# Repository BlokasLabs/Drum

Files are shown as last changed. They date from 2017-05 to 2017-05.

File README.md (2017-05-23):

# Drum

Drum is the Blokas Edition of the [Bleep Drum](http://bleeplabs.com/store/bleep-drum-midi/). It features a built-in speaker, so the beats won't stop flowing even when there's no headphones or external speaker at hand's reach!

## Building The Source Code

The firmware has dependencies on Bounce2 and MIDI libraries. They can easily be setup from within the Arduino IDE:

1. Go to Sketch -> Include Library -> Manage Libaries...
2. Install the following libraries:
    * [Bounce2](https://github.com/thomasfredericks/Bounce2) by Thomas Ouellet Fredericks with contributions from: Eric Lowry, Jim Schimpf and Tom Harkaway.
    * [MIDI Library](https://github.com/FortySevenEffects/arduino_midi_library) by Forty Seven Effects.

After dependencies are set up, just open DRUM/DRUM.ino in [Arduino IDE](https://www.arduino.cc/en/Main/Software) and it should build successfully.

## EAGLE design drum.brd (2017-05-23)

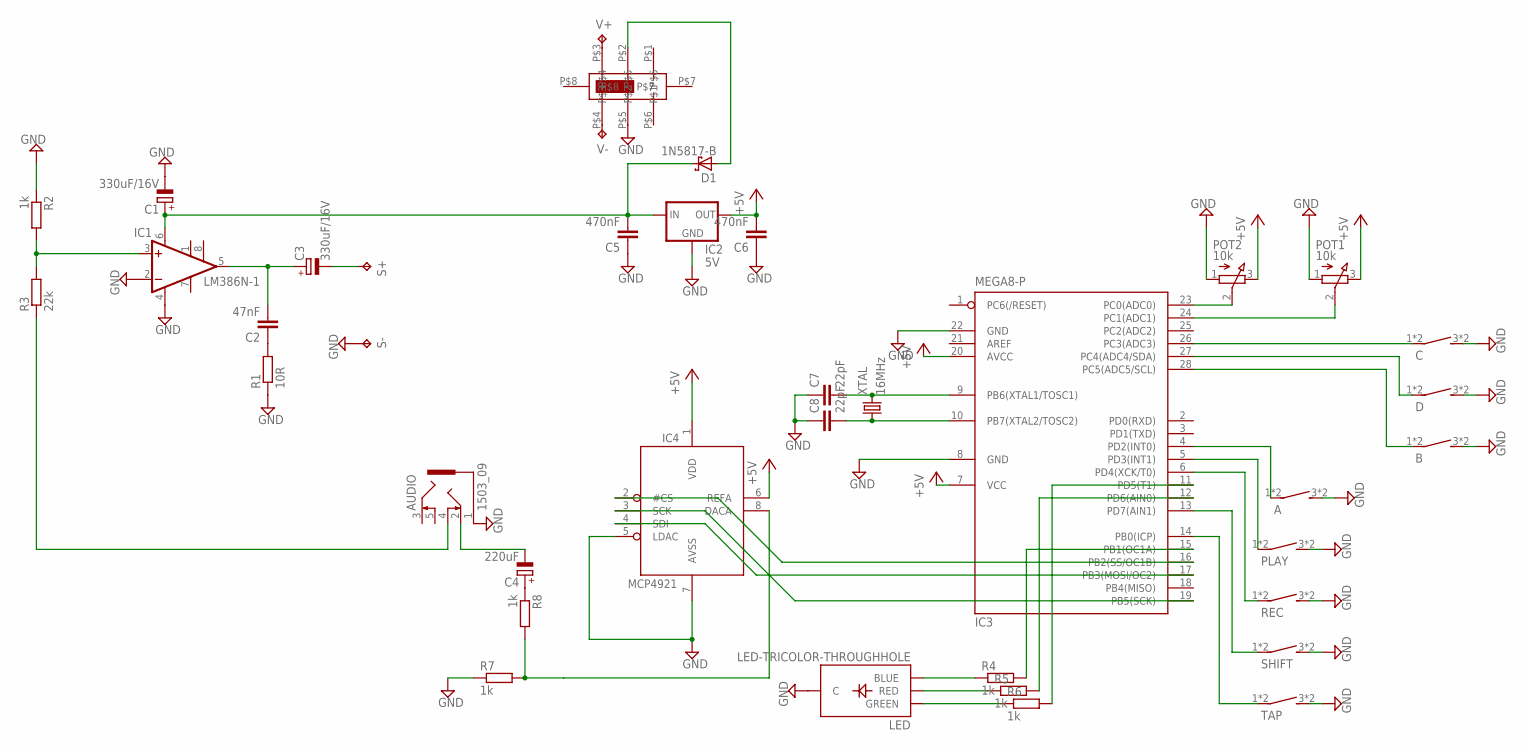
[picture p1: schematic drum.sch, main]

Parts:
A: D6R_SPSTB3F-4000; B3F-4000
AUDIO: 1503_09
B: D6R_SPSTB3F-4000; B3F-4000
C: D6R_SPSTB3F-4000; B3F-4000
C1, C3: 330uF/16V; E3,5-8
C2: 47nF; C050-024X044
C4: 220uF; E2,5-6
C5, C6: 470nF; C050-024X044
C7, C8: 22pF; C050-024X044
D: D6R_SPSTB3F-4000; B3F-4000
D1: 1N5817-B; DO41-7.6
IC1: LM386N-1; DIL08
IC2: 5V; 78LXX
IC3: MEGA8-P; DIL28-3
IC4: MCP4921; DIL08
LED: LED-TRICOLOR-THROUGHHOLE
PLAY: D6R_SPSTB3F-4000; B3F-4000
POT1, POT2: 10k; EVUFXJ
PWR: SLIDE_SW_DPDT; SS008B02P22
R1: 10R; 0207/10
R2, R4, R5, R6, R7, R8: 1k; 0207/10
R3: 22k; 0207/10
REC: D6R_SPSTB3F-4000; B3F-4000
S+: TPPAD1-17; P1-17
S-: TPPAD1-17; P1-17
SHIFT: D6R_SPSTB3F-4000; B3F-4000
TAP: D6R_SPSTB3F-4000; B3F-4000
V+: TPPAD1-17; P1-17
V-: TPPAD1-17; P1-17
XTAL: 16MHz; HC49/S

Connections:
+5V: C6.2, IC2.OUT, IC3.7 (VCC), IC3.20 (AVCC), IC4.1 (VDD), IC4.6 (REFA), POT1.3 (E), POT2.3 (E)
GND: A.3 (S), A.4 (S), AUDIO.1, B.3 (S), B.4 (S), C.3 (S), C.4 (S), C1.-, C5.1, C6.1, C7.1, C8.1, D.3 (S), D.4 (S), IC1.2 (-IN), IC1.4 (GND), IC2.GND, IC3.8 (GND), IC3.22 (GND), IC4.5 (LDAC), IC4.7 (AVSS), LED.GND (C), PLAY.3 (S), PLAY.4 (S), POT1.1 (A), POT2.1 (A), PWR.P$5, R1.1, R2.1, R7.1, REC.3 (S), REC.4 (S), S-.TP, SHIFT.3 (S), SHIFT.4 (S), TAP.3 (S), TAP.4 (S)
unnamed: C2.1, R1.2
unnamed: IC3.15 (PB1(OC1A)), R4.2
unnamed: IC3.12 (PD6(AIN0)), R5.2
unnamed: IC3.11 (PD5(T1)), R6.2
unnamed: IC3.5 (PD3(INT1)), PLAY.1, PLAY.2
unnamed: C1.+, C5.2, D1.C, IC1.6 (VS), IC2.IN
unnamed: IC3.17 (PB3(MOSI/OC2)), IC4.4 (SDI)
unnamed: A.1, A.2, IC3.4 (PD2(INT0))
unnamed: IC3.19 (PB5(SCK)), IC4.3 (SCK)
unnamed: IC3.23 (PC0(ADC0)), POT2.2 (S)
unnamed: IC3.24 (PC1(ADC1)), POT1.2 (S)
unnamed: C4.+, R8.1
unnamed: IC4.8 (DACA), R7.2, R8.2
unnamed: LED.GRN (BLUE), R4.1
unnamed: LED.BLU (RED), R5.1
unnamed: LED.RED (GREEN), R6.1
unnamed: C7.2, IC3.9 (PB6(XTAL1/TOSC1)), XTAL.2
unnamed: AUDIO.2, C4.-
unnamed: D.1, D.2, IC3.27 (PC4(ADC4/SDA))
unnamed: C8.2, IC3.10 (PB7(XTAL2/TOSC2)), XTAL.1
unnamed: C2.2, C3.+, IC1.5 (OUT)
unnamed: C3.-, S+.TP
unnamed: IC1.3 (+IN), R2.2, R3.2
unnamed: AUDIO.4, R3.1
unnamed: PWR.P$4, V-.TP
unnamed: PWR.P$3, V+.TP
unnamed: D1.A, PWR.P$2
unnamed: IC3.14 (PB0(ICP)), TAP.1, TAP.2
unnamed: IC3.6 (PD4(XCK/T0)), REC.1, REC.2
unnamed: IC3.13 (PD7(AIN1)), SHIFT.1, SHIFT.2
unnamed: C.1, C.2, IC3.26 (PC3(ADC3))
unnamed: B.1, B.2, IC3.28 (PC5(ADC5/SCL))
unnamed: IC3.16 (PB2(SS/OC1B)), IC4.2 (#CS)

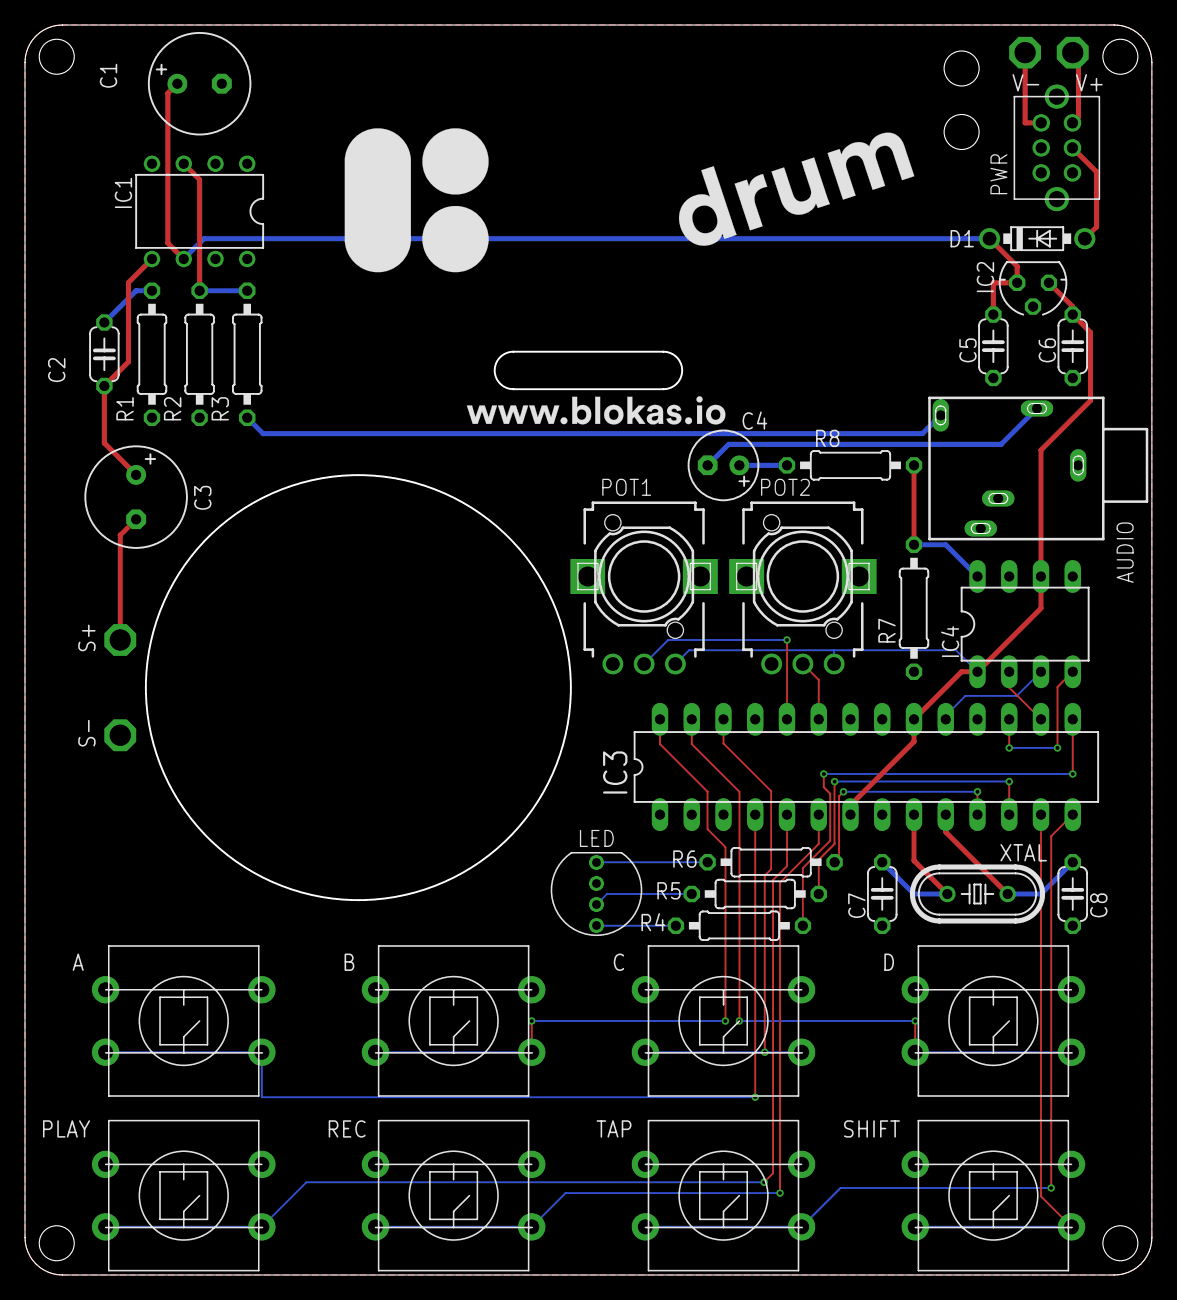
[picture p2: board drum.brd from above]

Board: 2 copper layers, 90.2 x 100.0 mm, 39 parts (0 on the bottom side), 35 nets.

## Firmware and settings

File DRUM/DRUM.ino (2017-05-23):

/*
The Bleep Drum v12
bleeplabs.com
August 2015
Dr. Bleep (John-Mike Reed) drbleep@bleeplabs.com

See http://bleeplabs.com/store/bleep-drum-midi/ for more info
All work licensed under a Creative Commons Attribution-ShareAlike 3.0

Now compatible with current versions of MIDI, bounce and pgmspace.
It is no longer necessary to edit MIDI.h

*/


#include <MIDI.h>
MIDI_CREATE_DEFAULT_INSTANCE();

#include <avr/pgmspace.h>
#include "samples.h"
#include <SPI.h>
#include <Bounce2.h>
#define BOUNCE_LOCK_OUT

Bounce debouncerRed = Bounce(); 
Bounce debouncerGreen = Bounce(); 
Bounce debouncerBlue = Bounce(); 
Bounce debouncerYellow = Bounce(); 

const char noise_table[] PROGMEM = {};

int sample_holder1, sample_holder2;
byte eee, ee, ef, eef;
byte shift, bankpg, bankpr, bout, rout, gout, prevpot2;
byte      banko = 0;
byte n1, n2;
int n3;
byte bankpb = 4;
byte beat;
int pot1 = 127;
int pot2 = 4;
long pot3, pot4;
int kick_sample, snare_sample, sample, hat_sample, noise_sample, bass_sample, B2_freq_sample, B1_freq_sample;
uint16_t increment, increment2, increment3, increment4, increment5, increment2v, increment4v;
uint32_t accumulator, accumulator2, accumulator3, accumulator4, accumulator5, accu_freq_1, accu_freq_2;
int rando;
//byte B1_sequence[16]={0,1,0,1 ,1,1,0,0 ,0,1,0,1 ,1,1,1,1};
//byte B4_sequence[16]={1,0,1,0 ,1,0,1,0 ,1,0,1,0 ,1,1,1,1};
byte B2_sequence[128] = {};
byte B3_sequence[128] = {};
byte B1_sequence[128] = {};
byte B4_sequence[128] = {
  1, 0, 0, 0 , 0, 0, 0, 0 , 1, 0, 0, 0 , 0, 0, 0, 0 , 1, 0, 0, 0 , 0, 0, 0, 0 , 1, 0, 0, 0 , 0, 0, 0, 0,
  1, 0, 0, 0 , 0, 0, 0, 0 , 1, 0, 0, 0 , 0, 0, 0, 0 , 1, 0, 0, 0 , 0, 0, 0, 0 , 1, 0, 0, 0 , 0, 0, 0, 0,
  0, 0, 0, 0 , 0, 0, 0, 0 , 0, 0, 0, 0 , 0, 0, 0, 0 , 0, 0, 0, 0 , 0, 0, 0, 0 , 0, 0, 0, 0 , 0, 0, 0, 0,
  1, 1, 1, 1 , 1, 1, 1, 1 , 1, 1, 1, 1 , 1, 1, 1, 1 , 0, 0, 0, 0 , 0, 0, 0, 0 , 0, 0, 0, 0 , 0, 0, 0, 0,
};

int B2_freq_sequence[128] = {
  0, 0, 0, 0 , 0, 0, 0, 0 , 0, 0, 0, 0 , 0, 0, 0, 0 , 0, 0, 0, 0 , 0, 0, 0, 0 , 0, 0, 0, 0 , 0, 0, 0, 0,
  0, 0, 0, 0 , 0, 0, 0, 0 , 0, 0, 0, 0 , 0, 0, 0, 0 , 0, 0, 0, 0 , 0, 0, 0, 0 , 0, 0, 0, 0 , 0, 0, 0, 0,
  0, 0, 0, 0 , 0, 0, 0, 0 , 0, 0, 0, 0 , 0, 0, 0, 0 , 0, 0, 0, 0 , 0, 0, 0, 0 , 0, 0, 0, 0 , 0, 0, 0, 0,
  0, 0, 0, 0 , 0, 0, 0, 0 , 0, 0, 0, 0 , 0, 0, 0, 0 , 0, 0, 0, 0 , 0, 0, 0, 0 , 0, 0, 0, 0 , 0, 0, 0, 0,

};
int B1_freq_sequence[128] = {};
int sample_sum;
int j, k, freq3, cc;
int kf, pf, holdkf, kfe;
int shiftcount = 0;
int t1, c1, count1, dd;
byte noise_type;
uint16_t index, index2, index3, index4, index5, index4b, index_freq_1, index_freq_2, index4bv;
uint16_t indexr, index2r, index3r, index4r, index4br, index2vr, index4vr;
int osc, oscc;
byte ledstep;
byte noise_mode = 1;
unsigned long freq, freq2;

int wavepot, lfopot, arppot;

byte loopstep = 0;
byte loopstepf = 0;

byte recordbutton, prevrecordbutton, record, looptrigger, prevloopstep, revbutton, prevrevbutton, preva, prevb;
int looprate;
//int clapbank[16]={1,0,0,0,1,0,1,0,1,1,1,1,0,0,0,0};
long prev, prev2, prev3;
byte playmode = 1;
byte play = 0;
byte playbutton, pplaybutton;
byte prevbanktrigger, banktrigger;
byte pkbutton, kbutton, B4_trigger, B4_latch, cbutton, pcbutton, B4_loop_trigger, B1_trigger, kick, B1_latch, clap, B1_loop_trigger, B4_seq_trigger, B3_seq_trigger;
byte ptbutton, tbutton, ttriger, B1_seq_trigger, B3_latch, B2_trigger, bc, B2_loop_trigger, B3_loop_trigger;
byte B2_latch, B3_trigger, B2_seq_trigger, pbutton, ppbutton;
byte kicktriggerv, B2_seq_latch, kickseqtriggerv,  B1_seq_latch, pewseqtriggerv, precordbutton;
byte measure, half;
byte recordmode = 1;
byte tap, tapbutton, ptapbutton, eigth;
long tapholder, prevtap;
unsigned long taptempo = 8000000;
unsigned long ratepot;
byte r, g, b, erase, e, preveigth;
//Bounce bouncertap = Bounce(8, 100);
byte trigger_input, trigger_output,   trigger_out_latch, tl;
byte onetime = 1;
//Bounce bouncer1 = Bounce(2, 200); //not actuall 2 seconds since timers are running at 64kHz.
//Bounce bouncer4 = Bounce(18, 200);
//Bounce bouncer2 = Bounce(19, 200);
//Bounce bouncer3 = Bounce( 17, 200);
byte button1, button2, button3, button4, tapb;
byte pbutton1, pbutton2, pbutton3, pbutton4, ptapb;
byte prev_trigger_in_read, trigger_in_read, tiggertempo, trigger_step, triggerled, ptrigger_step;

byte bf1, bf2, bf3, bf4, bft;
uint16_t midicc3 = 128;
uint16_t midicc4 = 157;
uint16_t midicc1, midicc2, midicc5, midicc6, midicc7, midicc8;

byte midi_note_check;

byte prevshift, shift_latch;
byte tick;
byte t;
long tapbank[4];
//int what,pwhat;
byte  mnote, mvelocity, miditap, pmiditap, miditap2, midistep, pmidistep, miditempo, midinoise;

unsigned long recordoffsettimer, offsetamount, taptempof;
int potX;

#define red_pin 2
#define blue_pin 19
#define green_pin 17
#define yellow_pin 18
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

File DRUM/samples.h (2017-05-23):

const char kick_table[] PROGMEM =
{
  127, 127, 127, 127, 127, 127, 127, 127, 127, 127, 127, 127, 127, 127, 127, 127, 126, 126, 126, 126, 126, 126, 126, 126, 126, 126, 126, 126, 126, 126, 126, 126, 126, 126, 126, 126, 126, 126, 126, 125, 125, 125, 125, 125, 125, 125, 125, 125, 125, 125, 125, 125, 125, 125, 125, 125, 125, 125, 125, 125, 124, 124, 124, 124, 124, 124, 124, 124, 124, 124, 124, 124, 124, 124, 124, 124, 124, 124, 124, 123, 123, 123, 123, 123, 123, 123, 123, 123, 123, 123, 123, 123, 123, 123, 123, 123, 122, 122, 122, 122, 122, 122, 122, 122, 122, 122, 122, 122, 122, 122, 122, 122, 122, 122, 121, 121, 121, 121, 121, 121, 121, 121, 121, 121, 121, 121, 121, 121, 121, 121, 121, 121, 121, 121, 121, 120, 120, 120, 120, 120, 120, 120, 120, 120, 120, 120, 120, 120, 120, 120, 120, 120, 120, 120, 120, 120, 120, 120, 120, 120, 120, 120, 120, 120, 120, 120, 120, 119, 120, 119, 119, 119, 119, 119, 119, 119, 119, 119, 119, 119, 119, 119, 119, 119, 119, 119, 120, 119, 120, 119, 120, 119, 122, 124, 125, 125, 127, 127, 128, 129, 129, 129, 128, 130, 134, 139, 145, 152, 158, 165, 181, 230, 255, 248, 230, 228, 240, 240, 233, 228, 228, 228, 224, 220, 217, 216, 216, 212, 209, 204, 199, 194, 192, 190, 189, 186, 184, 182, 179, 174, 168, 160, 153, 147, 142, 136, 130, 123, 116, 110, 103, 97, 92, 87, 82, 79, 75, 71, 67, 63, 58, 53, 50, 50, 49, 47, 45, 45, 44, 43, 42, 43, 42, 42, 42, 41, 41, 42, 45, 47, 48, 50, 52, 54, 55, 58, 61, 61, 63, 65, 66, 68, 71, 74, 77, 80, 85, 89, 93, 96, 99, 104, 108, 112, 117, 121, 125, 129, 132, 137, 143, 149, 155, 162, 166, 171, 176, 182, 186, 191, 194, 195, 196, 196, 197, 198, 200, 201, 201, 201, 201, 202, 202, 203, 203, 202, 203, 202, 199, 198, 197, 196, 194, 191, 188, 186, 186, 186, 185, 183, 180, 177, 174, 172, 169, 165, 161, 155, 151, 148, 142, 136, 130, 126, 121, 117, 113, 107, 103, 100, 96, 94, 91, 88, 86, 83, 80, 79, 76, 74, 71, 68, 64, 62, 60, 57, 55, 56, 57, 55, 54, 54, 54, 53, 53, 52, 51, 50, 50, 52, 53, 54, 55, 56, 55, 55, 56, 59, 60, 60, 61, 62, 63, 63, 64, 65, 66, 66, 68, 71, 72, 73, 74, 76, 79, 81, 82, 84, 89, 92, 96, 98, 101, 104, 107, 111, 114, 118, 120, 123, 127, 130, 132, 135, 137, 139, 141, 144, 147, 150, 154, 158, 162, 165, 168, 171, 175, 178, 182, 186, 188, 191, 193, 196, 199, 201, 204, 206, 207, 208, 209, 210, 210, 210, 209, 209, 209, 210, 211, 210, 210, 211, 211, 211, 211, 212, 213, 213, 213, 212, 210, 208, 205, 204, 203, 201, 200, 199, 198, 196, 194, 192, 191, 190, 188, 187, 185, 185, 183, 181, 179, 177, 174, 172, 169, 166, 162, 159, 156, 153, 149, 146, 143, 140, 136, 133, 130, 127, 124, 121, 118, 116, 113, 110, 108, 105, 103, 100, 98, 95, 93, 91, 88, 86, 84, 82, 80, 78, 76, 75, 73, 71, 70, 68, 67, 65, 64, 63, 62, 61, 60, 59, 58, 57, 57, 56, 55, 55, 55, 54, 54, 54, 54, 54, 54, 54, 55, 55, 55, 56, 56, 57, 57, 58, 58, 59, 59, 60, 60, 61, 62, 62, 63, 64, 64, 65, 66, 66, 67, 68, 68, 69, 70, 71, 71, 72, 73, 74, 75, 76, 77, 79, 80, 81, 83, 84, 86, 87, 89, 90, 92, 94, 96, 97, 99, 101, 103, 105, 107, 109, 111, 113, 115, 117, 119, 121, 123, 125, 127, 129, 131, 133, 135, 137, 139, 141, 143, 145, 147, 149, 151, 153, 155, 158, 160, 162, 164, 166, 168, 170, 172, 174, 176, 179, 180, 182, 184, 186, 188, 190, 191, 193, 194, 196, 197, 198, 200, 201, 202, 203, 204, 204, 205, 206, 206, 207, 207, 208, 208, 208, 209, 209, 209, 209, 209, 209, 209, 209, 208, 208, 208, 208, 207, 207, 206, 206, 205, 205, 204, 204, 203, 202, 202, 201, 200, 199, 199, 198, 197, 196, 195, 194, 193, 192, 191, 190, 189, 188, 187, 185, 184, 183, 182, 181, 179, 178, 177, 175, 174, 172, 171, 169, 168, 166, 164, 163, 161, 159, 157, 156, 154, 152, 150, 148, 145, 143, 141, 139, 137, 135, 132, 130, 128, 126, 124, 122, 119, 117, 115, 113, 111, 109, 107, 105, 103, 102, 100, 98, 96, 95, 93, 92, 90, 89, 87, 86, 84, 83, 81, 80, 79, 78, 76, 75, 74, 73, 71, 70, 69, 68, 67, 66, 65, 64, 63, 62, 61, 60, 59, 58, 57, 57, 56, 55, 55, 54, 54, 53, 53, 53, 52, 52, 52, 52, 52, 52, 52, 52, 52, 52, 52, 52, 53, 53, 53, 53, 54, 54, 54, 54, 55, 55, 55, 56, 56, 57, 57, 57, 58, 58, 59, 59, 60, 60, 61, 61, 62, 62, 63, 63, 64, 65, 65, 66, 66, 67, 68, 69, 69, 70, 71, 71, 72, 73, 74, 74, 75, 76, 77, 77, 78, 79, 80, 81, 81, 82, 83, 84, 85, 86, 86, 87, 88, 89, 90, 91, 92, 93, 94, 95, 96, 98, 99, 100, 101, 102, 104, 105, 106, 108, 109, 110, 112, 113, 115, 116, 117, 119, 120, 122, 123, 125, 126, 128, 129, 131, 132, 134, 135, 136, 138, 139, 141, 142, 144, 145, 146, 148, 149, 150, 152, 153, 155, 156, 157, 158, 160, 161, 162, 164, 165, 166, 168, 169, 170, 172, 173, 174, 176, 177, 178, 180, 181, 182, 183, 185, 186, 187, 188, 190, 191, 192, 193, 194, 195, 196, 197, 198, 199, 200, 201, 202, 202, 203, 204, 204, 205, 205, 206, 206, 206, 206, 207, 207, 207, 207, 207, 207, 207, 207, 207, 207, 207, 206, 206, 206, 206, 206, 205, 205, 205, 205, 204, 204, 204, 204, 203, 203, 203, 202, 202, 202, 201, 201, 200, 200, 200, 199, 198, 198, 197, 197, 196, 195, 195, 194, 193, 192, 192, 191, 190, 189, 188, 187, 187, 186, 185, 184, 183, 182, 181, 180, 179, 178, 177, 176, 175, 175, 174, 173, 172, 171, 170, 169, 168, 167, 166, 165, 164, 163, 162, 161, 160, 158, 157, 156, 155, 153, 152, 151, 149, 148, 146, 145, 143, 142, 140, 139, 137, 135, 134, 132, 131, 129, 127, 126, 124, 123, 121, 119, 118, 116, 115, 113, 112, 110, 109, 108, 106, 105, 104, 102, 101, 100, 98, 97, 96, 95, 94, 93, 91, 90, 89, 88, 87, 86, 85, 84, 83, 82, 81, 80, 79, 78, 77, 76, 75, 75, 74, 73, 72, 71, 70, 70, 69, 68, 68, 67, 66, 66, 65, 64, 64, 63, 62, 62, 61, 61, 60, 60, 59, 59, 59, 58, 58, 57, 57, 57, 57, 56, 56, 56, 56, 56, 56, 56, 56, 56, 56, 56, 56, 56, 56, 56, 56, 57, 57, 57, 57, 58, 58, 58, 59, 59, 59, 60, 60, 60, 61, 61, 61, 62, 62, 62, 63, 63, 63, 64, 64, 64, 65, 65, 65, 66, 66, 67, 67, 67, 68, 68, 69, 69, 70, 70, 71, 71, 72, 73, 73, 74, 74, 75, 75, 76, 77, 77, 78, 79, 79, 80, 80, 81, 82, 82, 83, 84, 84, 85, 85, 86, 87, 87, 88, 88, 89, 90, 90, 91, 92, 92, 93, 94, 95, 95, 96, 97, 98, 98, 99, 100, 101, 102, 103, 104, 105, 106, 107, 108, 109, 110, 111, 112, 113, 114, 115, 116, 117, 118, 119, 121, 122, 123, 124, 125, 126, 127, 129, 130, 131, 132, 133, 134, 135, 136, 137, 139, 140, 141, 142, 143, 144, 145, 146, 147, 148, 149, 151, 152, 153, 154, 155, 156, 157, 158, 159, 160, 161, 162, 163, 164, 165, 166, 167, 168, 169, 170, 171, 172, 173, 174, 175, 176, 177, 178, 179, 180, 181, 182, 183, 184, 185, 186, 187, 187, 188, 189, 190, 191, 192, 192, 193, 194, 195, 195, 196, 197, 197, 198, 198, 199, 199, 200, 200, 201, 201, 201, 201, 202, 202, 202, 202, 202, 202, 202, 202, 202, 202, 202, 201, 201, 201, 201, 201, 200, 200, 200, 200, 199, 199, 199, 198, 198, 198, 197, 197, 197, 196, 196, 196, 195, 195, 195, 194, 194, 194, 193, 193, 192, 192, 191, 191, 191, 190, 190, 189, 188, 188, 187, 187, 186, 185, 185, 184, 183, 183, 182, 181, 180, 180, 179, 178, 177, 176, 176, 175, 174, 173, 172, 171, 171, 170, 169, 168, 167, 167, 166, 165, 164, 163, 163, 162, 161, 160, 159, 158, 158, 157, 156, 155, 154, 153, 152, 151, 150, 149, 148, 147, 146, 145, 144, 143, 142, 141, 139, 138, 137, 136,
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
